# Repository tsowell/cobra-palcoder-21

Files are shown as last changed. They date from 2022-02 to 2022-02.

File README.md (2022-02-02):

(Vezi [README-ro.md](README-ro.md) pentru o traducere greșită în română.)

# Cobra PAL Coder v2.1

These are KiCad files for the [PAL coder for the Cobra computer analyzed by
YO3GHM and described on cobrasov.com][PAL coder v2].

[PAL coder v2]: http://cobrasov.com/CoBra%20Project/pal2.html

The board connects to the PAL coder connector present on versions 0.2+ of the
motherboard, but it has an additional header, J2, on top to receive the VI
signal.  I use a one-pin ribbon cable to connect the PAL coder to the VI signal
on the video connector at the back of the motherboard.

The output PAL signal is passed through to the motherboard and also to an
optional BNC connector on the PAL board itself.

One notable modification to the version documented by YO3GHM is that this
version passes HB instead of NHB (because NHB is not on the PAL coder
connector) into the PROM, and the PROM contents must be different in order to
accomodate this.

Also, this revision uses the VCR signal from the motherboard instead of VNY.

NOTE: This revision has not been tested yet.  It includes some simple fixes for
problems in the [previous revision][5211970], which is known to work.

[5211970]: https://github.com/tsowell/cobra-palcoder-21/tree/5211970

## Images

Schematic

<p float="left">
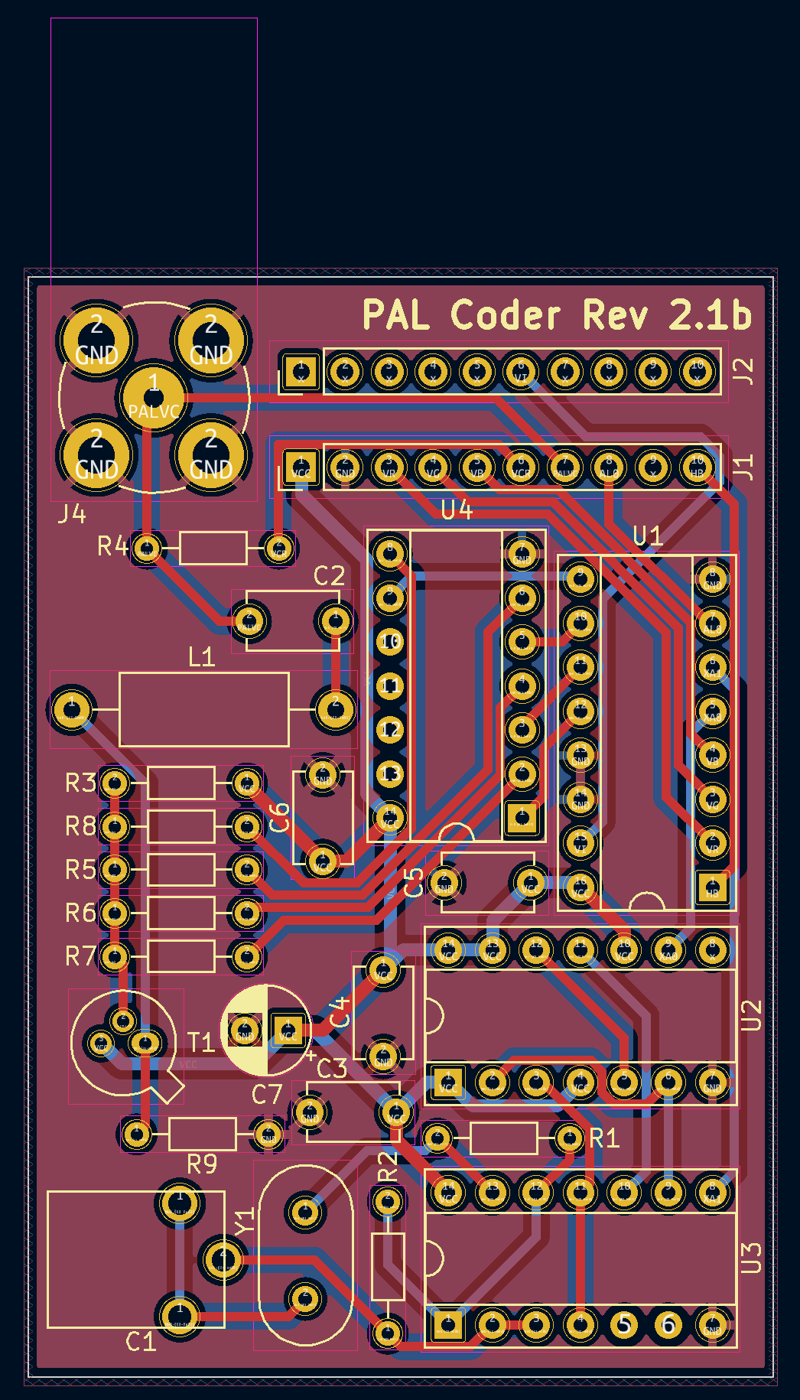
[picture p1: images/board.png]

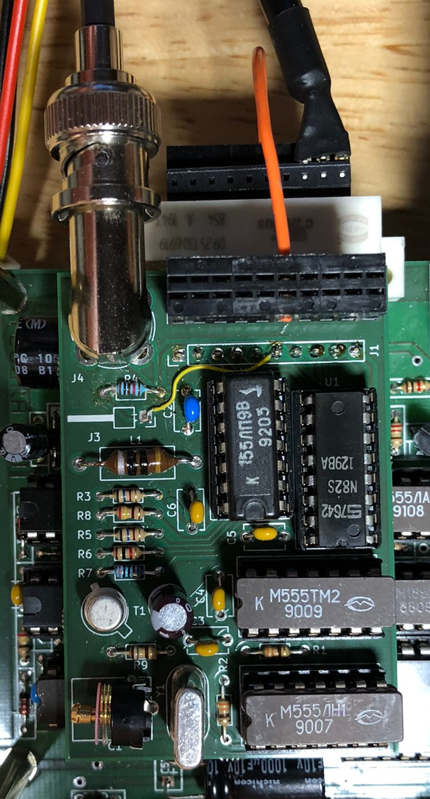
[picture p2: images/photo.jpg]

</p>

The photograph is from the last revision with bodges.

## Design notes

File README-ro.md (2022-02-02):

# Codor PAL v2.1 pentru Cobra

Acestea sunt fișiere KiCad pentru [Codorul PAL pentru calculatorul Cobra
analizat de YO3GHM și descris pe cobrasov.com][Codor PAL v2].

[Codor PAL v2]: http://cobrasov.com/CoBra%20Project/pal2-ro.html

Circuitul se conectează la conectorul codor PAL care există în versiune 0.2+ de
placa de bază, dar are un header suplimentar, J2, deasupra să primească signal
semnal VI.  Folosec un cablu panglică cu un singur pin să-l contectez la semnal
VI pe conectorul PAL video în spatele plăcii.

Samnal de ieșire PAL trece prin la placa de bază și de asemenea un conector
opțional BNC pe placa de circuit PAL.

O modificare notabilă versiunii documentat de YO3GHM este că în această
versiune, HB în loc de NHB întră PROMul, și conținutul PROMului trebuie să se
schimbe pentru acest.

Altfel, această revizuire ar trebuie să fi o reproducere corectă a circuitului
lui YO3GHM.

De asemnea, această revizuire folosește semnal VCR în loc de semnal VNY.

NOTĂ: Încă această revizuire nu a fost testat.  Include niște remedieri pentru
probleme în [revizuirea anterioară][5211970], care se știe că funcționa.

[5211970]: https://github.com/tsowell/cobra-palcoder-21/tree/5211970

## Imagine

Schematic

<p float="left">


</p>

Fotograful este din ultima revizuire cu remedieri.

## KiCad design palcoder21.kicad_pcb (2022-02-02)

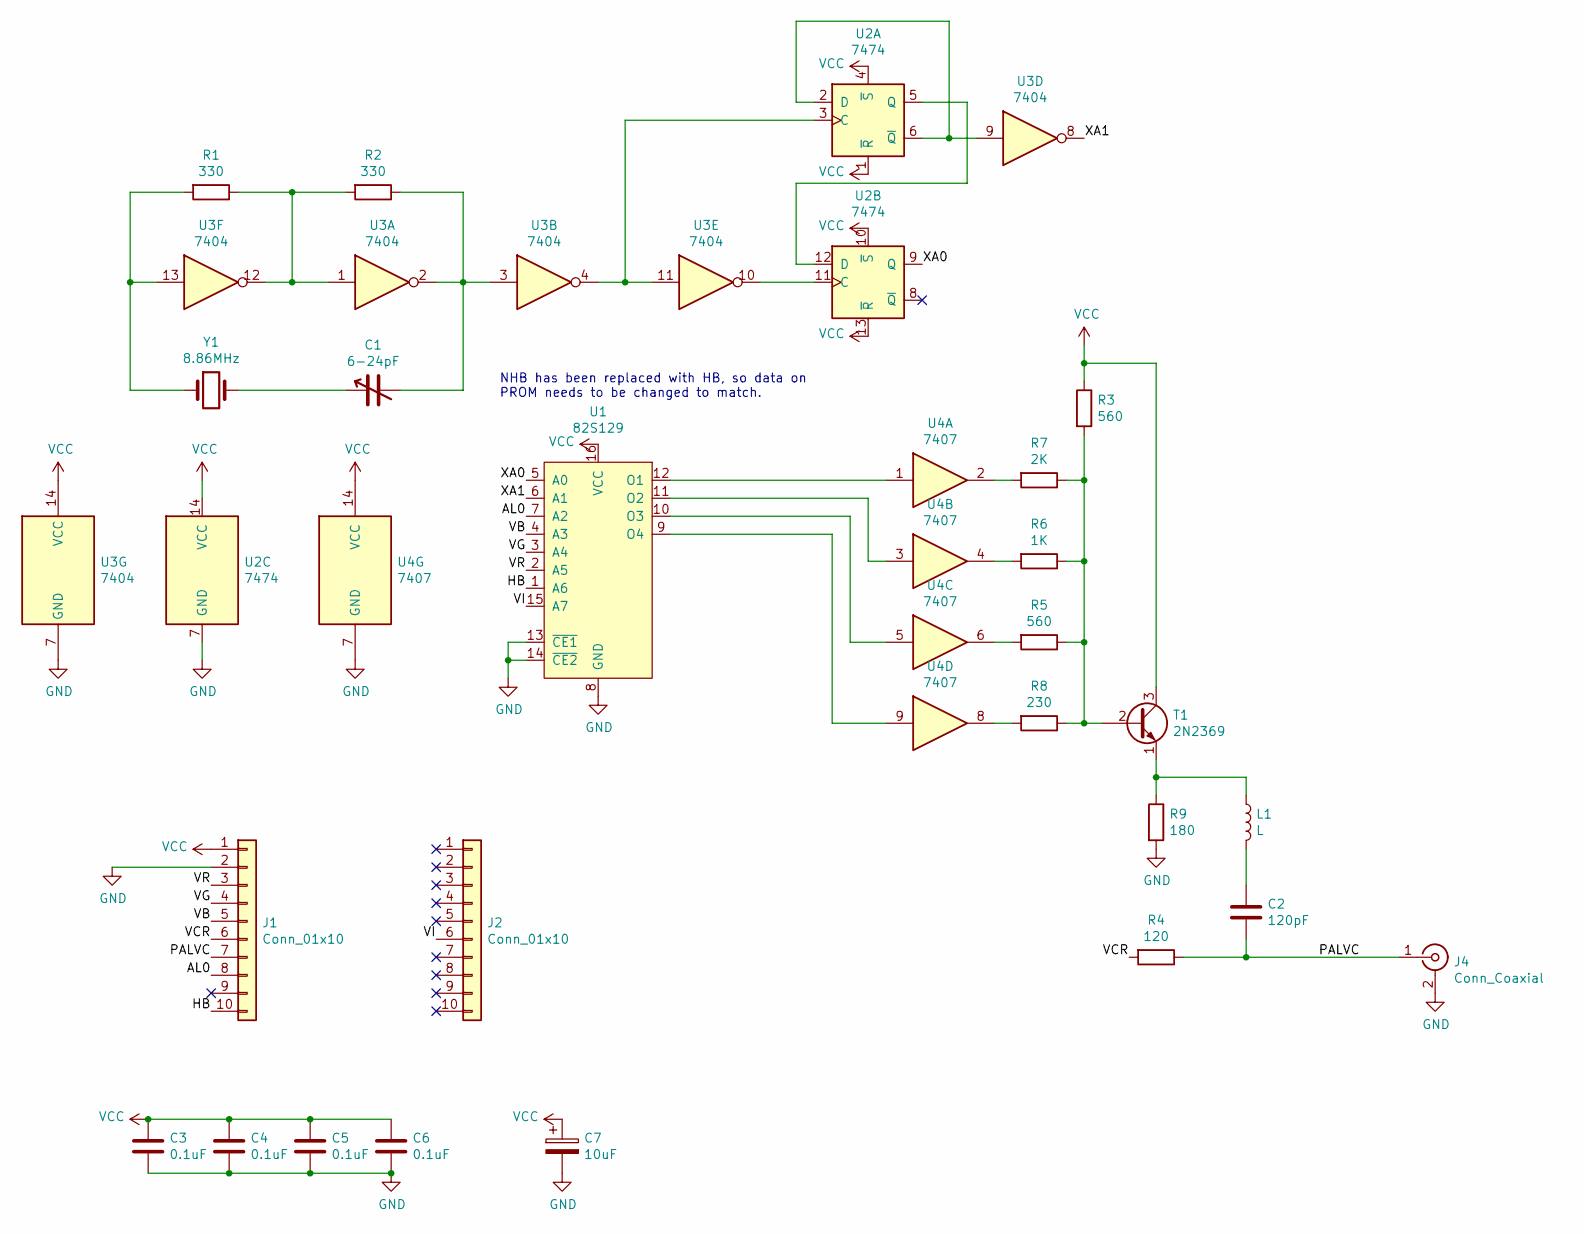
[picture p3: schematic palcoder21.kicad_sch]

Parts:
C1: 6-24pF; GYB27000
C2: 120pF; C_Disc_D5.1mm_W3.2mm_P5.00mm
C3, C4, C5, C6: 0.1uF; C_Disc_D5.1mm_W3.2mm_P5.00mm
C7: 10uF; CP_Radial_D5.0mm_P2.50mm
J1, J2: Conn_01x10; PinHeader_1x10_P2.54mm_Vertical
J4: Conn_Coaxial; BNC_TEConnectivity_BNC_TEConnectivity_5413558-1
L1: L; L_Axial_L9.5mm_D4.0mm_P15.24mm_Horizontal_Fastron_SMCC
R1, R2: 330; R_Axial_DIN0204_L3.6mm_D1.6mm_P7.62mm_Horizontal
R3, R5: 560; R_Axial_DIN0204_L3.6mm_D1.6mm_P7.62mm_Horizontal
R4: 120; R_Axial_DIN0204_L3.6mm_D1.6mm_P7.62mm_Horizontal
R6: 1K; R_Axial_DIN0204_L3.6mm_D1.6mm_P7.62mm_Horizontal
R7: 2K; R_Axial_DIN0204_L3.6mm_D1.6mm_P7.62mm_Horizontal
R8: 230; R_Axial_DIN0204_L3.6mm_D1.6mm_P7.62mm_Horizontal
R9: 180; R_Axial_DIN0204_L3.6mm_D1.6mm_P7.62mm_Horizontal
T1: 2N2369; TO-18-3
U1: 82S129; DIP-16_W7.62mm_Socket
U2: 7474; DIP-14_W7.62mm_Socket
U3: 7404; DIP-14_W7.62mm_Socket
U4: 7407; DIP-14_W7.62mm_Socket
Y1: 8.86MHz; Resonator-2Pin_W10.0mm_H5.0mm

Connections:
/AL0: J1.8, U1.7 (A2)
/HB: J1.10, U1.1 (A6)
/PALVC: C2.2, J1.7, J4.1 (In), R4.1
/VB: J1.5, U1.4 (A3)
/VCR: J1.6, R4.2
/VG: J1.4, U1.3 (A4)
/VI: J2.6, U1.15 (A7)
/VR: J1.3, U1.2 (A5)
/XA0: U1.5 (A0), U2.9 (Q)
/XA1: U1.6 (A1), U3.8
GND: C3.2, C4.2, C5.2, C6.2, C7.2, J1.2, J4.2 (Ext), R9.2, U1.8 (GND), U1.13 (~CE1), U1.14 (~CE2), U2.7 (GND), U3.7 (GND), U4.7 (GND)
unnamed: C1.1, Y1.2
unnamed: C1.2, R2.1, U3.2, U3.3
unnamed: C2.1, L1.2
unnamed: L1.1, R9.1, T1.1 (E)
unnamed: R1.1, R2.2, U3.1, U3.12
unnamed: R1.2, U3.13, Y1.1
unnamed: R3.2, R5.1, R6.1, R7.1, R8.1, T1.2 (B)
unnamed: R5.2, U4.6
unnamed: R6.2, U4.4
unnamed: R7.2, U4.2
unnamed: R8.2, U4.8
unnamed: U1.9 (O4), U4.9
unnamed: U1.10 (O3), U4.5
unnamed: U1.11 (O2), U4.3
unnamed: U1.12 (O1), U4.1
unnamed: U2.2 (D), U2.6 (~Q), U3.9
unnamed: U2.3 (C), U3.4, U3.11
unnamed: U2.11 (C), U3.10
unnamed: U2.5 (Q), U2.12 (D)
VCC: C3.1, C4.1, C5.1, C6.1, C7.1, J1.1, R3.1, T1.3 (C), U1.16 (VCC), U2.1 (~R), U2.4 (~S), U2.10 (~S), U2.13 (~R), U2.14 (VCC), U3.14 (VCC), U4.14 (VCC)

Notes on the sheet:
NHB has been replaced with HB, so data on PROM needs to be changed to match.

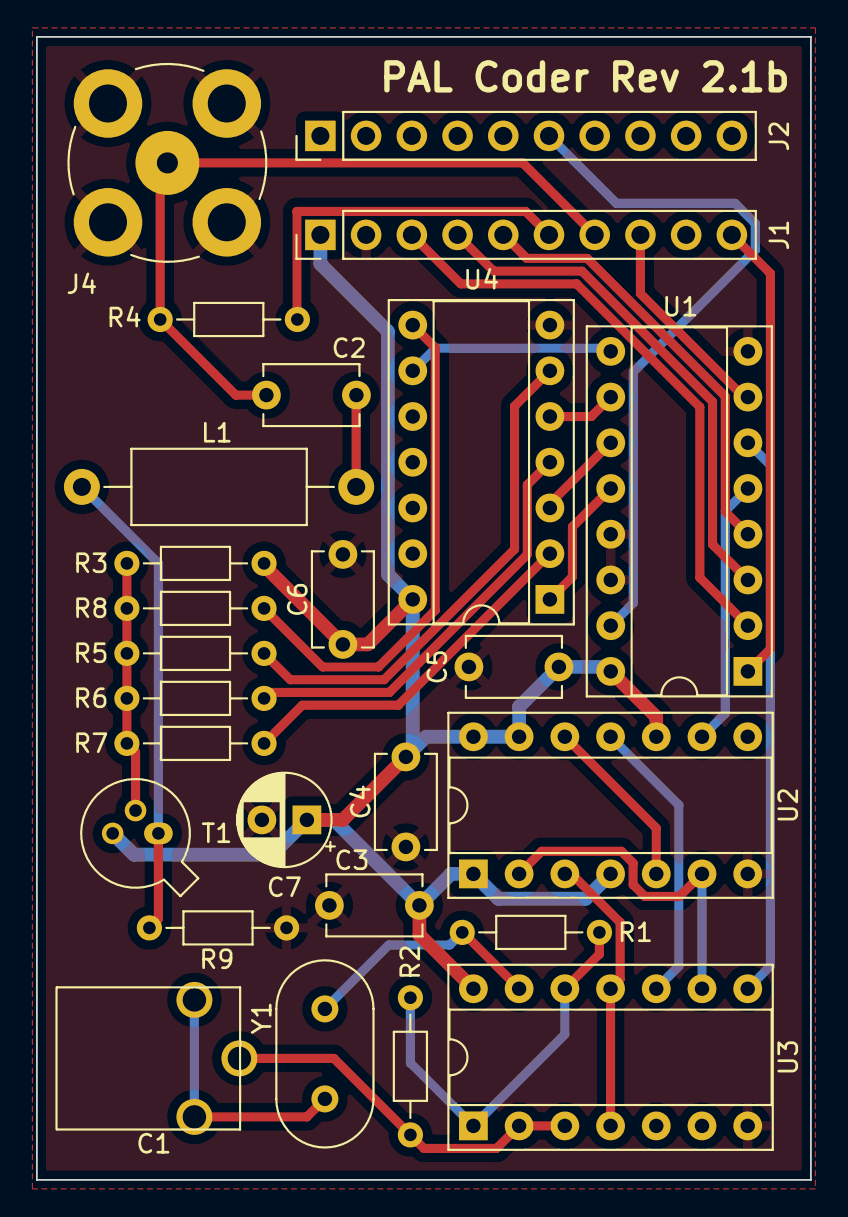
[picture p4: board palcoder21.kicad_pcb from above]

Board: 2 copper layers, 43.0 x 63.5 mm, 26 parts (0 on the bottom side), 31 nets.
